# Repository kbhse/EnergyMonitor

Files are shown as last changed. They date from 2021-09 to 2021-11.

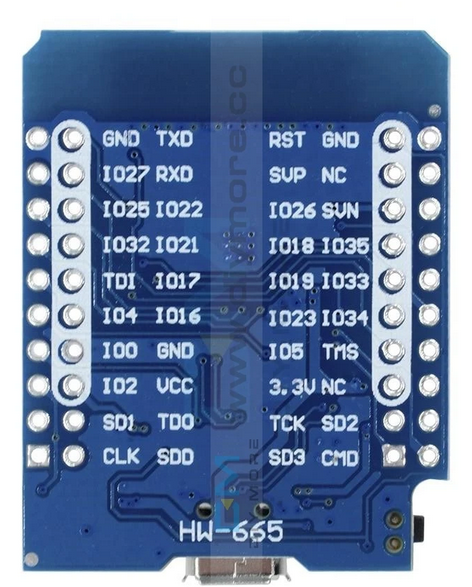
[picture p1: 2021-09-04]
KiCad/v1.1/images/Aideepen Wemos D1 ESP32.PNG

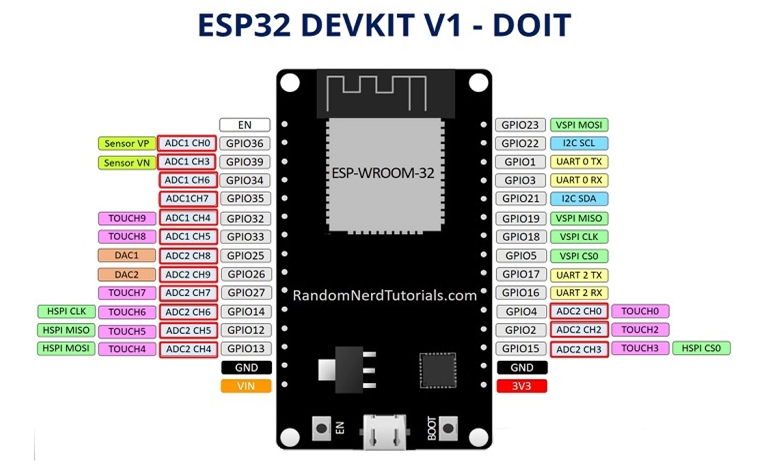
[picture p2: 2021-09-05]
KiCad/v1.1/images/ESP32_DEVKIT_V1.png

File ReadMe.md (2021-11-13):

pcb 3D 02

 &nbsp;
 
* Schematic and PCB design in [KiCad](https://www.kicad.org/)

* Hardware design in [SolidWorks](https://www.solidworks.com/domain/design-engineering)

* C++ code on [PlatformIO](https://docs.platformio.org/en/latest/what-is-platformio.html) IDE

* 3D prints [Prusa i3 MK3S+](https://www.prusa3d.com)

&nbsp;

 **ESP32 based energy monitor**

Samples voltage and current waveform at 2500 Hz.
The voltage waveform is sampled from an AC/AC 9v wallplug adapter and the current waveforms with current transformers clamped round live (or neutral) conductors.

Capacity: 240v, 3 circuits up tp 95 amps each.

Intergrated into a [MQTT](https://en.wikipedia.org/wiki/MQTT) [IoT](https://en.wikipedia.org/wiki/Internet_of_things) sensor network with [Node-RED](https://nodered.org/), [InfluxDB](https://www.influxdata.com/) and [Grafana](https://grafana.com/) servers.

Uses the [EmonLib library](https://github.com/openenergymonitor/EmonLib)

[An Introduction to AC Power](https://learn.openenergymonitor.org/electricity-monitoring/ac-power-theory/introduction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)

The **ESP32** is a low-cost, low-power [system on a chip](https://en.wikipedia.org/wiki/System_on_a_chip "System on a chip") [microcontroller](https://en.wikipedia.org/wiki/Microcontroller "Microcontroller") with integrated Wi-Fi, created and developed by Espressif Systems



Specification:

- Xtensa dual-core 32-bit LX6 microprocessor
- 240 MHz
- 520 KiB SRAM, 448 KiB ROM, 16 KiB SRAM in RTC
- Ultra low power co-processor
- Wi-Fi: 802.11 b/g/n
- 34 × programmable [GPIO](https://en.wikipedia.org/wiki/General-purpose_input/output)s
- 12-bit [SAR ADC](https://en.wikipedia.org/wiki/Successive-approximation_ADC) up to 18 channels
- 2 × 8-bit [DAC](https://en.wikipedia.org/wiki/Digital-to-analog_converter)s
- 10 × touch sensors (capacitive sensing GPIOs)
- 4 × [SPI](https://en.wikipedia.org/wiki/Serial_Peripheral_Interface)
- 2 × [I²S](https://en.wikipedia.org/wiki/I%C2%B2S) interfaces
- 2 × [I²C](https://en.wikipedia.org/wiki/I%C2%B2C) interfaces
- 3 × [UART](https://en.wikipedia.org/wiki/Universal_asynchronous_receiver-transmitter)
- SD/SDIO/CE-ATA/MMC/eMMC host controller
- SDIO/SPI slave controller
- Ethernet MAC interface with dedicated DMA and IEEE 1588
- Precision Time Protocol support
- [CAN bus](https://en.wikipedia.org/wiki/CAN_bus) 2.0
- Infrared remote controller (TX/RX, up to 8 channels)
- Motor [PWM](https://en.wikipedia.org/wiki/Pulse-width_modulation)
- LED PWM (up to 16 channels)
- [Hall effect](https://en.wikipedia.org/wiki/Hall_effect) sensor
- Ultra low power analog pre-amplifier
- IEEE 802.11 standard security features all supported, including [WPA](https://en.wikipedia.org/wiki/Wi-Fi_Protected_Access), - [WPA2](https://en.wikipedia.org/wiki/Wi-Fi_Protected_Access), [WPA3](https://en.wikipedia.org/wiki/Wi-Fi_Protected_Access) and [WAPI](https://en.wikipedia.org/wiki/WLAN_Authentication_and_Privacy_Infrastructure)
- [Secure boot](https://docs.espressif.com/projects/esp-idf/en/latest/esp32/security/secure-boot-v1.html)
- [Flash encryption](https://docs.espressif.com/projects/esp-idf/en/latest/esp32/security/flash-encryption.html)
- 1024-bit [OTP](https://en.wikipedia.org/wiki/One-time_password)
- Cryptographic hardware acceleration: [AES](https://en.wikipedia.org/wiki/Advanced_Encryption_Standard), [SHA-2](https://en.wikipedia.org/wiki/SHA-2), [RSA](https://en.wikipedia.org/wiki/RSA_(cryptosystem)), [elliptic curve cryptography (ECC)](https://en.wikipedia.org/wiki/Elliptic-curve_cryptography), [random number generator (RNG)](https://en.wikipedia.org/wiki/Random_number_generation)
- Internal [low-dropout regulator](https://en.wikipedia.org/wiki/Low-dropout_regulator)
- Individual power domain for [RTC](https://en.wikipedia.org/wiki/Real-time_clock)
- 5 μA deep sleep current
- Wake up from GPIO interrupt, timer, ADC measurements, capacitive touch sensor interrupt

&nbsp;

**PCB:**

- CAD: [KiCad](https://www.kicad.org/)
- Production: [JLCPCB](https://jlcpcb.com/)

pcb 3D

board

board

GndA

PCB_GNDA

Gnd

PCB_GND

[JLCPCB](https://jlcpcb.com/)

pcb

Production Progress

20210930_182721_50%

20211003_025516_50%

20211003_025620_50%

&nbsp;

**Case design** (WIP):

CAD: [SolidWorks](https://www.solidworks.com/domain/design-engineering)

Slicer: [PrusaSlicer](https://www.prusa3d.com/prusaslicer/)

Printer: [Prusa i3 MK3S+](https://www.prusa3d.com)

- Material: E-DA [PLA](https://en.wikipedia.org/wiki/Polylactic_acid)
- Nozzle: 0.4mm
- Layer Height: 0.2mm
- Infill: 20% cubic
- Support: optional
- Filament: 21m, 63g
- Print Time: 5hr 48m

Dimensions (LxWxH): 110x58x35 mm

EnergyMonitor Case v1 2 transparent

EnergyMonitor Case v1 2



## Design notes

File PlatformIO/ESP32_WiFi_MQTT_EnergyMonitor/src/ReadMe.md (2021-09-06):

Notes:

- [x] use a different library for SHT30 (with crc error checking)

- [x] make wifi and mqtt non-blocking

WiFi:

https://www.esp8266.com/viewtopic.php?p=71077

https://arduino-esp8266.readthedocs.io/en/latest/esp8266wifi/generic-examples.html

MQTT:

https://github.com/knolleary/pubsubclient/blob/master/examples/mqtt_reconnect_nonblocking/mqtt_reconnect_nonblocking.ino

3. remote reboot ESP32

4. PID control

5. sht30 sample rate & I2C speed vs cable length https://github.com/espressif/arduino-esp32/issues/1395

6. pubsub qos http://www.steves-internet-guide.com/using-arduino-pubsub-mqtt-client/

7. 06/01/21 19:00 v01.04 running

8. Sometimes getting -54 on ssrState! use boolean data type

9. if it restarts it will go back to default low and high setPoints !!! need NodeRED globals?

10. ~~do I need the wemos relay??~~

11. add remote restart via subscribe to topic ssrHeater1/restart

12. perhaps it should check for setPoints regularly (if mqtt not reliable and it doesn't update from Node-RED publish)

Don't block critical thermostat function !!

non-blocking WiFi:

If connection is established, and then lost for some reason, ESP will automatically reconnect to the last used access point once it is again back on-line. This will be done automatically by Wi-Fi library, without any user intervention.
So the old code would only be blocking on startup or restart (in setup() call to setup_wifi()) if there is no WiFi because code is waiting to report that the connection has been established.
This code: `while (WiFi.status() != WL_CONNECTED)` could loop forever if no WiFi connection established.
Don't need to report connection established so just get rid of that code.

NB test it works if ESP8266 starts up with no WiFi available. does a blink in loop work?

for an event driven solution that reports connection/disconnection without blocking critical functionality

see : https://arduino-esp8266.readthedocs.io/en/latest/esp8266wifi/readme.html#quick-start

non-blocking mqtt https://github.com/knolleary/pubsubclient/blob/master/examples/mqtt_reconnect_nonblocking/mqtt_reconnect_nonblocking.ino

ChangeLog

01.00

01.05 change default setPoints

01.06 added publish (re)start message (to track restarts) in setup()

01.07 on (re)startup (in setup()) publish request for the current setPoints but don't wait for them (non-blocking).

they will overwrite the defaults in callback() if/when messages arrive. take care in NodeRED that the values won't fail the sanity check (in callback()) which would revert to defaults!

PROBLEM WITH MQTT MULTIPLE CONNECTIONS:

change the ESP device ID

Here's how it looks:

	if (client.connect("ESP8266Client")) {

Can do it like this:

	if (client.connect("ESP1_Office")) {

Then, for the other ESP:

	if (client.connect("ESP2_Garage")) {

That should solve MQTT multiple connections problem.

- [x] If it starts without a wifi signal need code in loop() to periodically try to connect, simlar to MQTT server connection

- [x] change name from client to MQTTclient

- [ ] setup in weatherstation

- [x] callback in energy monitor

MQTT:

https://github.com/knolleary/pubsubclient

https://randomnerdtutorials.com/raspberry-pi-publishing-mqtt-messages-to-esp8266/

EmonLib:

https://savjee.be/2019/07/Home-Energy-Monitor-ESP32-CT-Sensor-Emonlib/

- [ ] grafana mqtt buttons
- [ ] calculate power factors in Node-RED instead of mcu

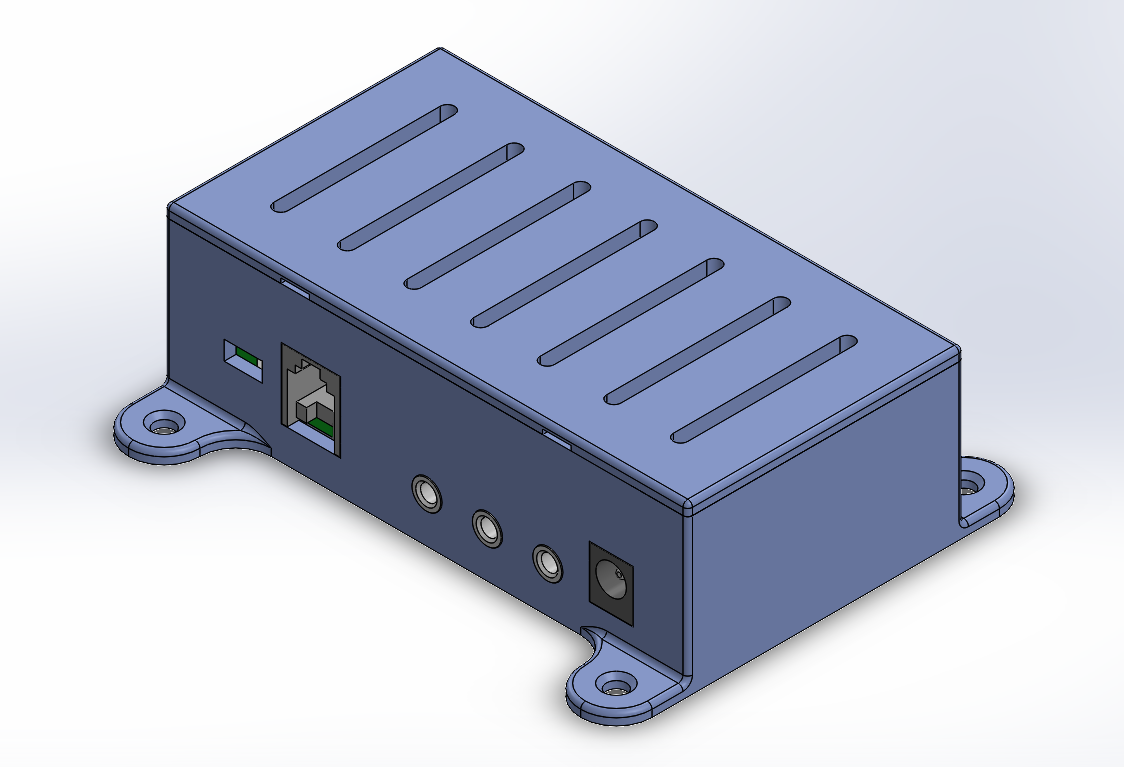
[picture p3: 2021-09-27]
Solidworks/images/EnergyMonitor Case v1.0.PNG

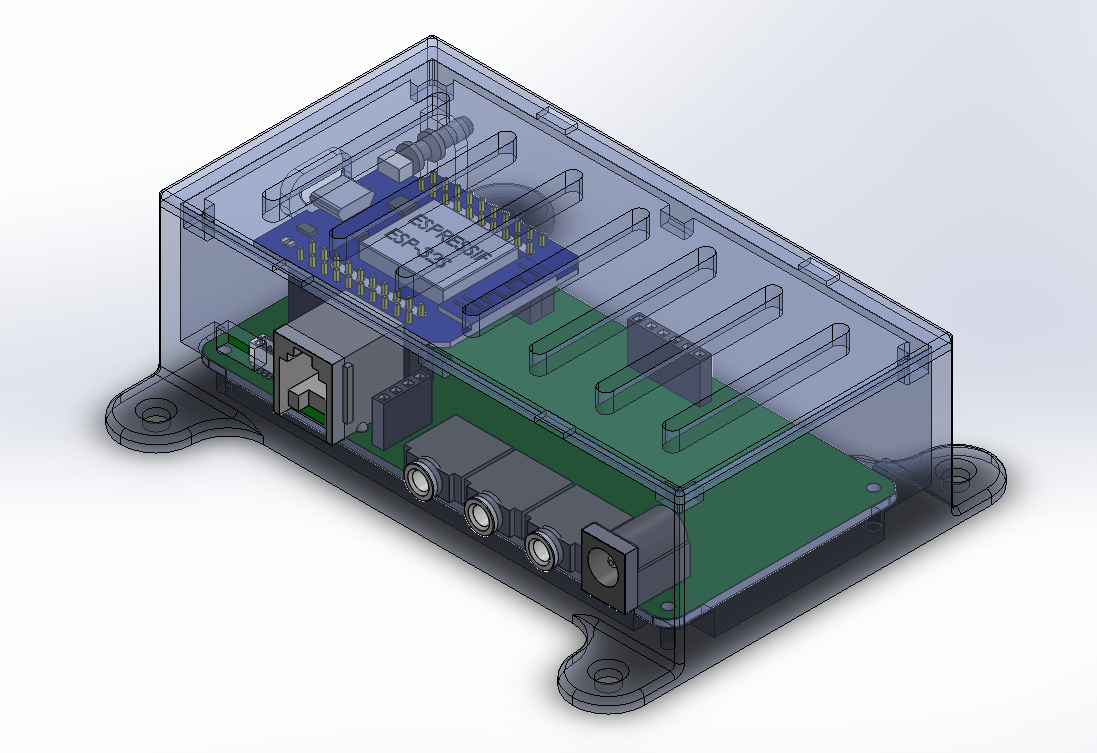
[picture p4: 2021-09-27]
Solidworks/images/EnergyMonitor Case v1.0 transparent.PNG

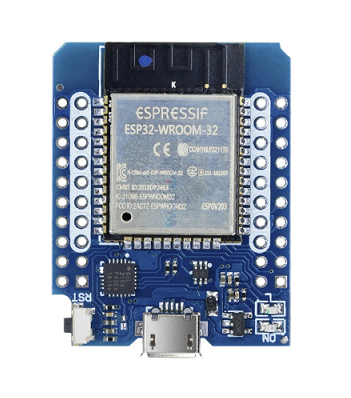
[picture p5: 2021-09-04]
KiCad/v1.1/images/Aideepen Wemos D1 ESP32_top.PNG

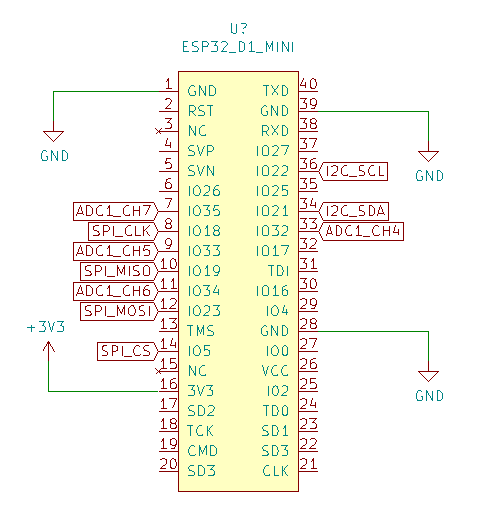
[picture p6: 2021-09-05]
KiCad/v1.1/images/ESP32_D1_MINI Symbol.PNG

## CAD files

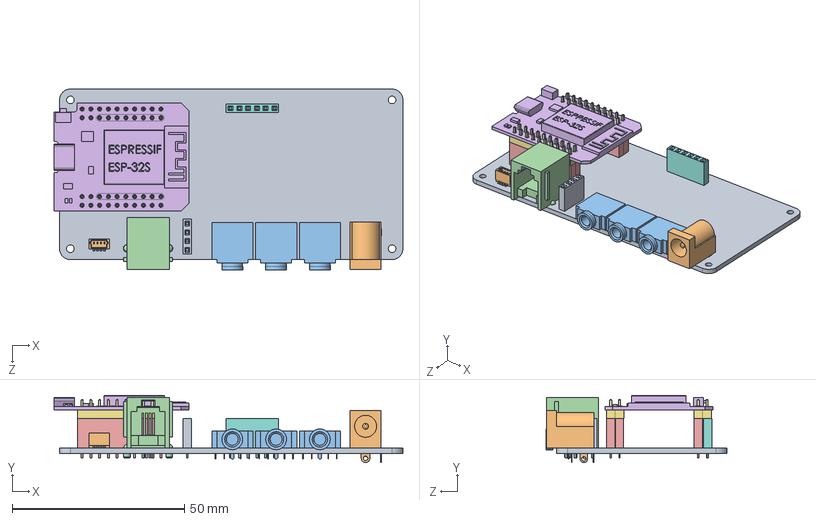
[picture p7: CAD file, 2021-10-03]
Solidworks/pcb_v1.0.SLDASM
101.3 x 19.5 x 52.5 mm
pcb_v1.0
5.5x2.1mm 3P DC Power Jack PCB Mount Female Socket
PCB Mount 3.5mm 5 Pin Socket x 3
RJ9 4P4C (#C026)
header sockets 1x10 x 4
ESP32 D1 mini
header pins 1x10 x 4
header sockets 1x6
header sockets 1x4
JST_SH_BM04B_SRDD_TB_04x1.00mm

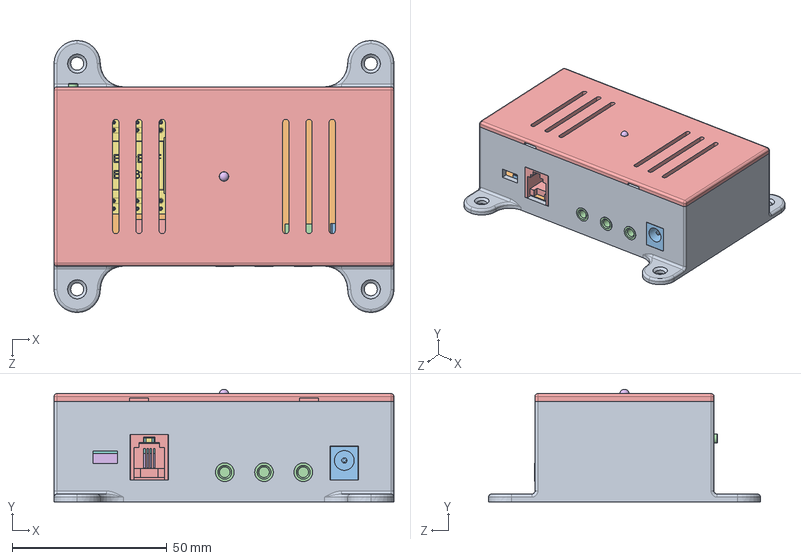
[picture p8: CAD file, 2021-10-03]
Solidworks/EnergyMonitor v1.2.SLDASM
110.0 x 36.4 x 88.0 mm
EnergyMonitor Case v1.2
pcb_v1.0
5.5x2.1mm 3P DC Power Jack PCB Mount Female Socket
PCB Mount 3.5mm 5 Pin Socket x 3
RJ9 4P4C (#C026)
header sockets 1x10 x 4
ESP32 D1 mini
header pins 1x10 x 4
header sockets 1x6
header sockets 1x4
JST_SH_BM04B_SRDD_TB_04x1.00mm
reset pin
EnergyMonitor Case top v1.2
LED

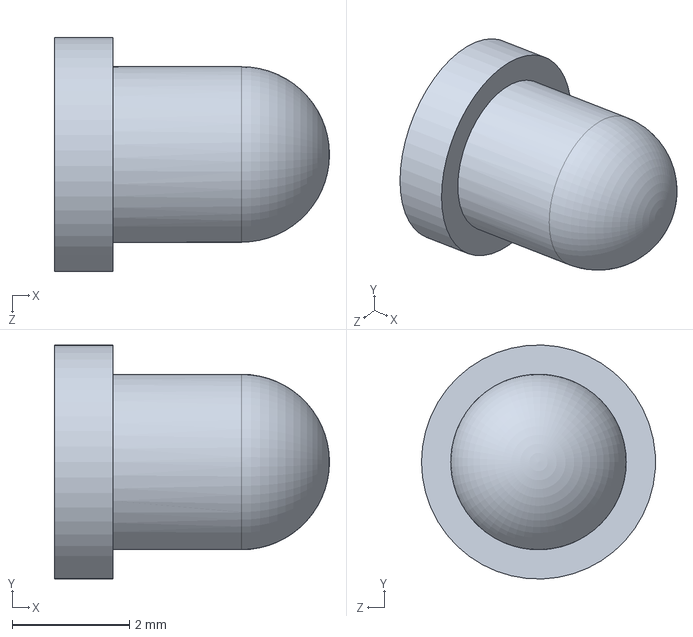
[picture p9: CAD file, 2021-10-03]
Solidworks/LED.SLDPRT
4.70 x 4.00 x 4.00 mm

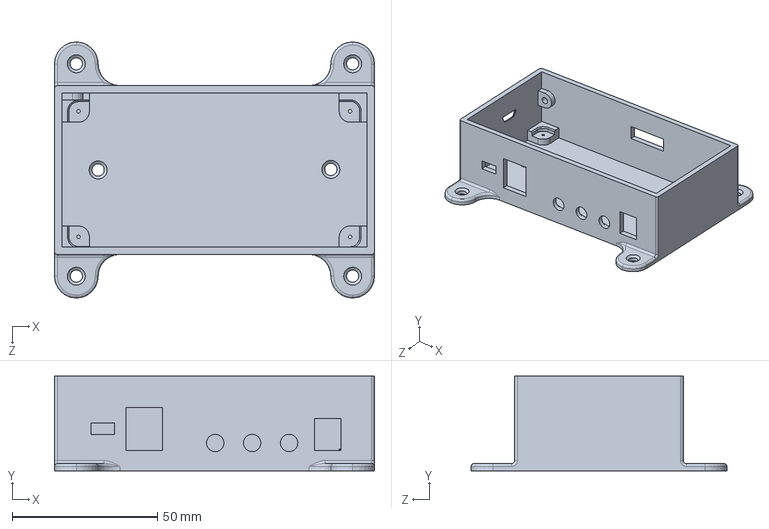
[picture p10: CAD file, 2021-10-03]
Solidworks/EnergyMonitor Case v1.2.SLDPRT
110.0 x 32.5 x 88.0 mm

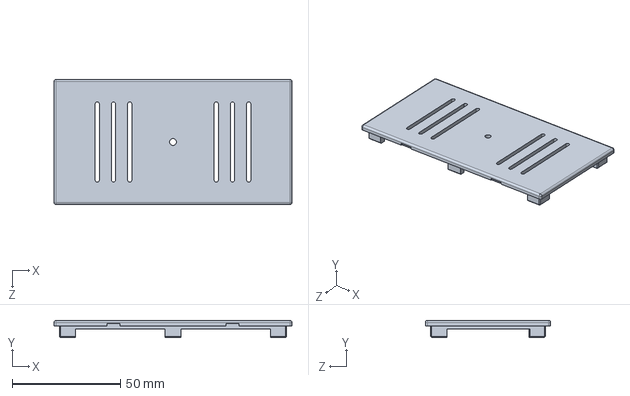
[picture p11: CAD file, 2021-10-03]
Solidworks/EnergyMonitor Case top v1.2.SLDPRT
110.0 x 8.00 x 58.0 mm

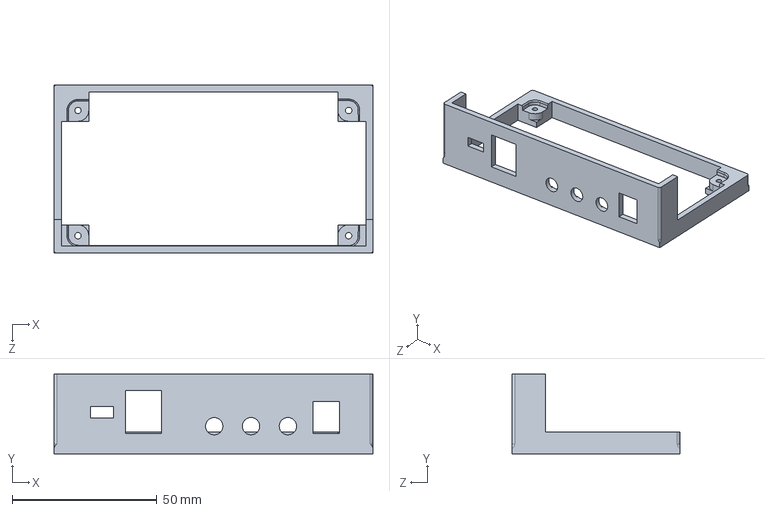
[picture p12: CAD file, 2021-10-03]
Solidworks/EnergyMonitor Case v1.0 jig.SLDPRT
110.0 x 27.5 x 58.0 mm

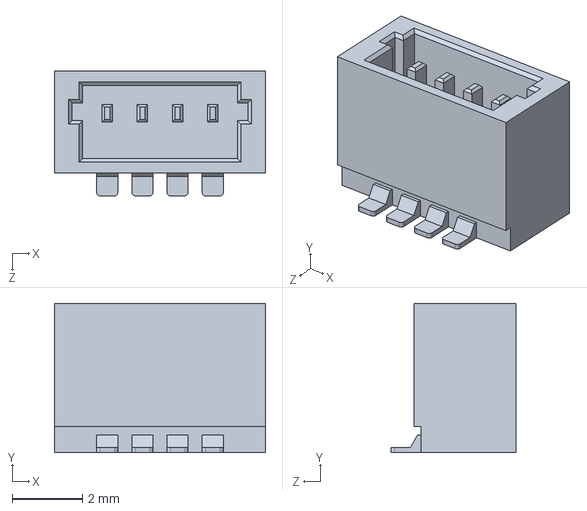
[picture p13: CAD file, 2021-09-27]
Solidworks/JST_SH_BM04B_SRDD_TB_04x1.00mm.SLDPRT
6.00 x 4.25 x 3.55 mm

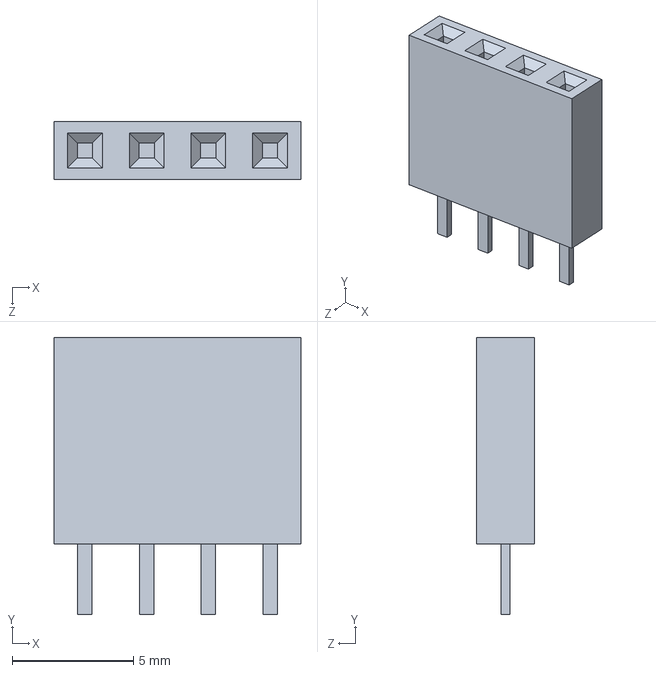
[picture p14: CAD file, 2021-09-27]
Solidworks/header sockets 1x4.SLDPRT
10.2 x 11.4 x 2.40 mm

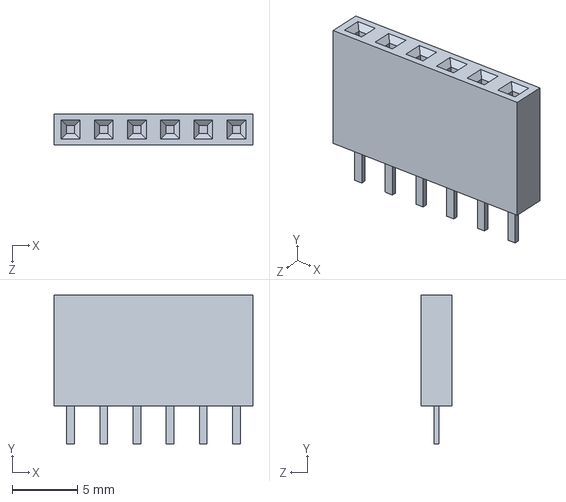
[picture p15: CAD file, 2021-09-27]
Solidworks/header sockets 1x6.SLDPRT
15.2 x 11.4 x 2.40 mm

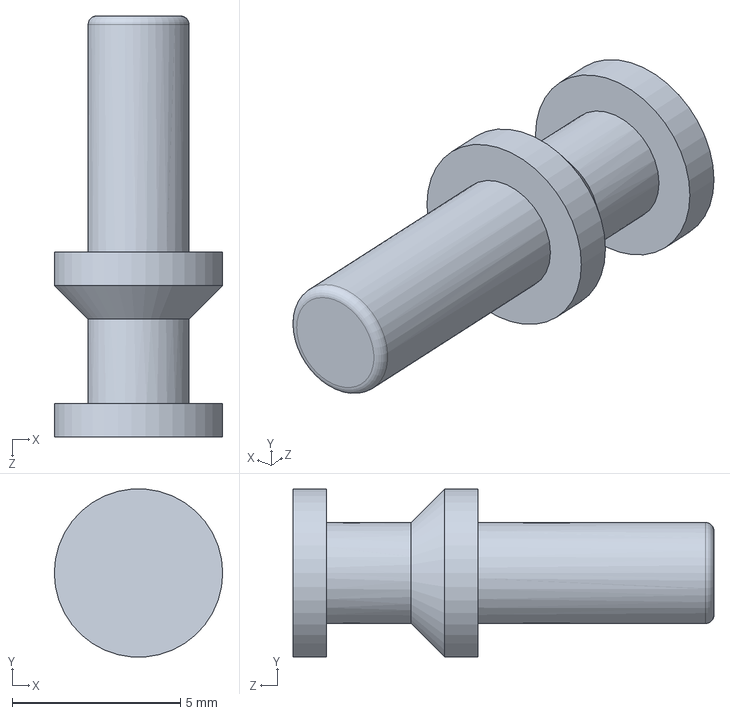
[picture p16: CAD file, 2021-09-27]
Solidworks/reset pin.SLDPRT
5.00 x 4.98 x 12.5 mm

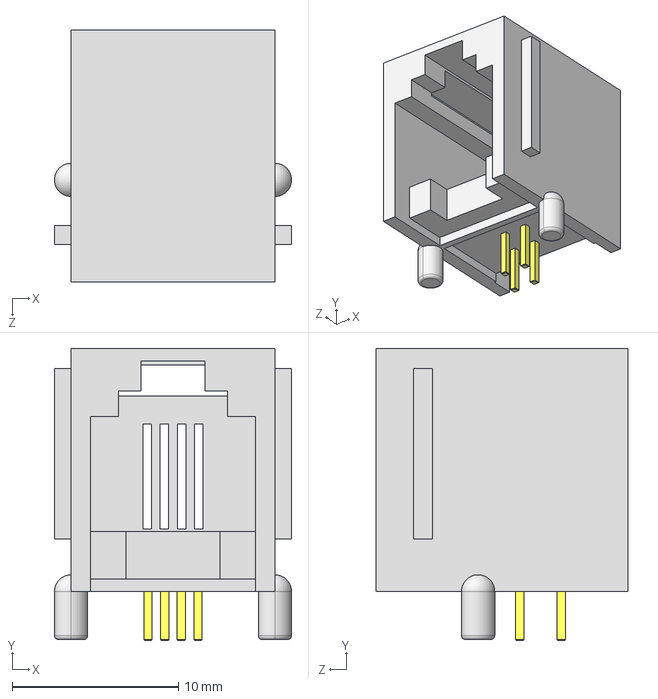
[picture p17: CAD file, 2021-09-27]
Solidworks/RJ9 4P4C (#C026).STEP
14.3 x 17.5 x 15.1 mm

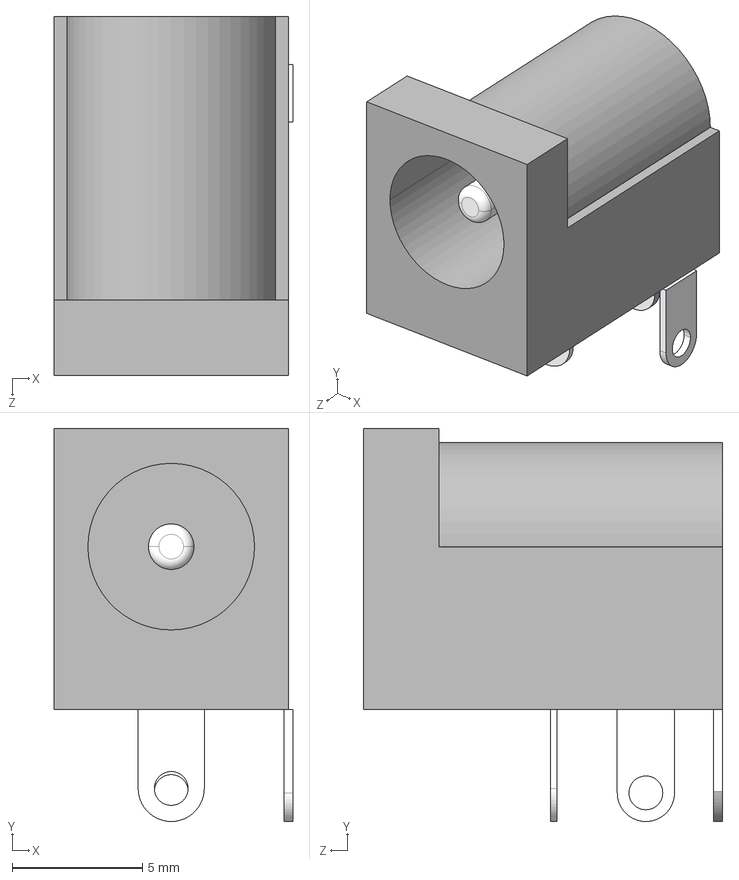
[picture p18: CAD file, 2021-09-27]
Solidworks/5.5x2.1mm 3P DC Power Jack PCB Mount Female Socket.STEP
9.17 x 15.1 x 13.8 mm

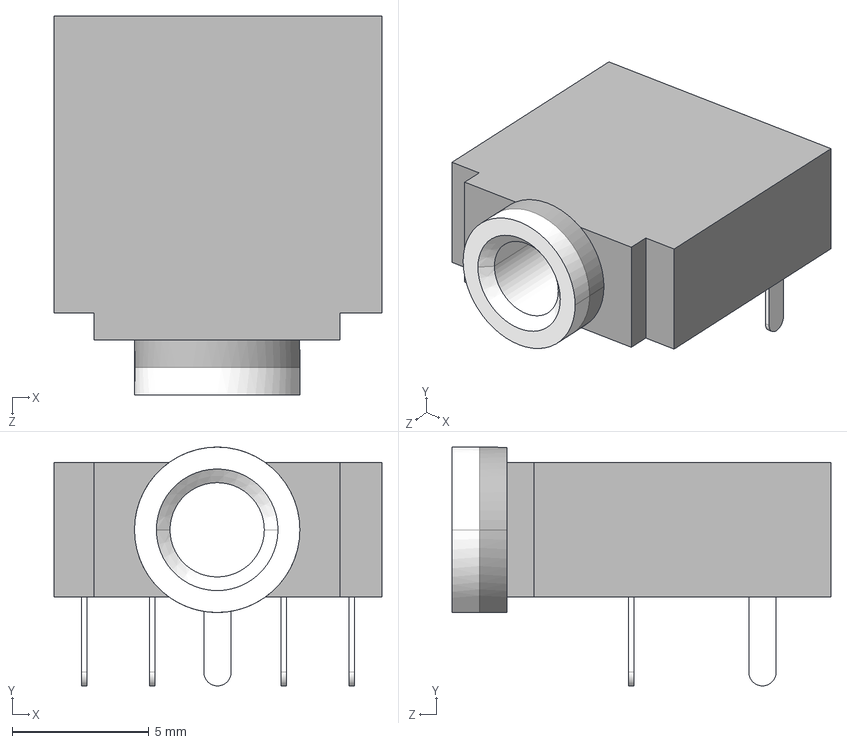
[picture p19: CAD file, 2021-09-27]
Solidworks/PCB Mount 3.5mm 5 Pin Socket.STEP
12.0 x 8.74 x 13.8 mm

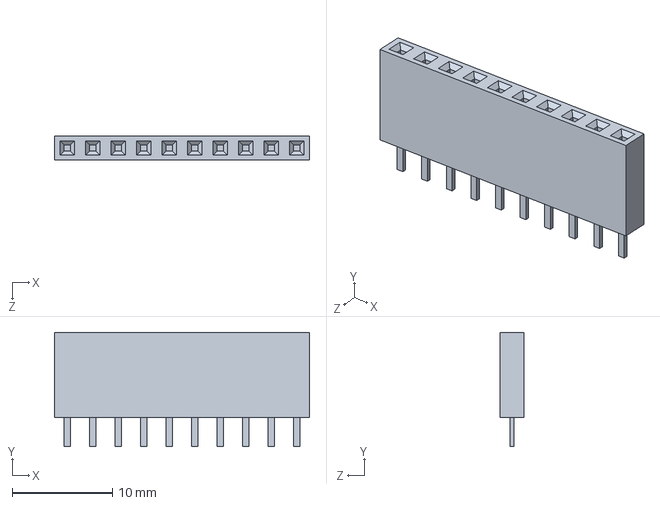
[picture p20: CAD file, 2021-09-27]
Solidworks/header sockets 1x10.SLDPRT
25.4 x 11.4 x 2.40 mm

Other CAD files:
Solidworks/header pins 1x10.SLDPRT
Solidworks/ESP32 D1 mini.STEP
Solidworks/EnergyMonitor v1.0.SLDASM
Solidworks/EnergyMonitor Case top v1.1.SLDPRT
Solidworks/5.5x2.1mm 3P DC Power Jack PCB Mount Female Socket.SLDPRT
Solidworks/ESP32 D1 mini.SLDASM
Solidworks/ESP32 D1 mini.SLDPRT
Solidworks/EnergyMonitor Case top v1.0.SLDPRT
Solidworks/EnergyMonitor Case v1.0.SLDPRT
Solidworks/PCB Mount 3.5mm 5 Pin Socket.SLDPRT
Solidworks/RJ9 4P4C (#C026).SLDPRT
Solidworks/pcb_v1.0.SLDPRT
Solidworks/stl/EnergyMonitor Case top v1.0.STL
Solidworks/stl/EnergyMonitor Case top v1.1.STL
Solidworks/stl/EnergyMonitor Case top v1.2.STL
Solidworks/stl/EnergyMonitor Case v1.0 jig.SLDPRT
Solidworks/stl/EnergyMonitor Case v1.0 jig.STL
Solidworks/stl/EnergyMonitor Case v1.0.STL
Solidworks/stl/EnergyMonitor Case v1.2.STL
Solidworks/stl/reset pin.STL

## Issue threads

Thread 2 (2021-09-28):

v1.0 Case design

kbhse, 2021-09-28:
front exit for JST SH 4 pin connector cable for I2C
rear exit for JST XH 6 pin connector cable for GPIO/SPI
plugs for exits when not in use
recesses for captive M2 hex nuts
adjust height
provision for (some interchangable) labels for ports
reset pin
LED on outer surface?

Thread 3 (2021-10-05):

Powering ESP32 D1 mini from external 3.3v supply

kbhse, 2021-10-05:
This doesn't work. Perhaps removing LDO from ESP32 D1 mini might work but not a great solution as would need external (non USB) power supply when programming ESP32.

Try replacing HT7333 3.3V LDO with HT7350 SOT-89 5V LDO and jumper to VCC input on ESP32 D1 mini.
HT7350 on order.

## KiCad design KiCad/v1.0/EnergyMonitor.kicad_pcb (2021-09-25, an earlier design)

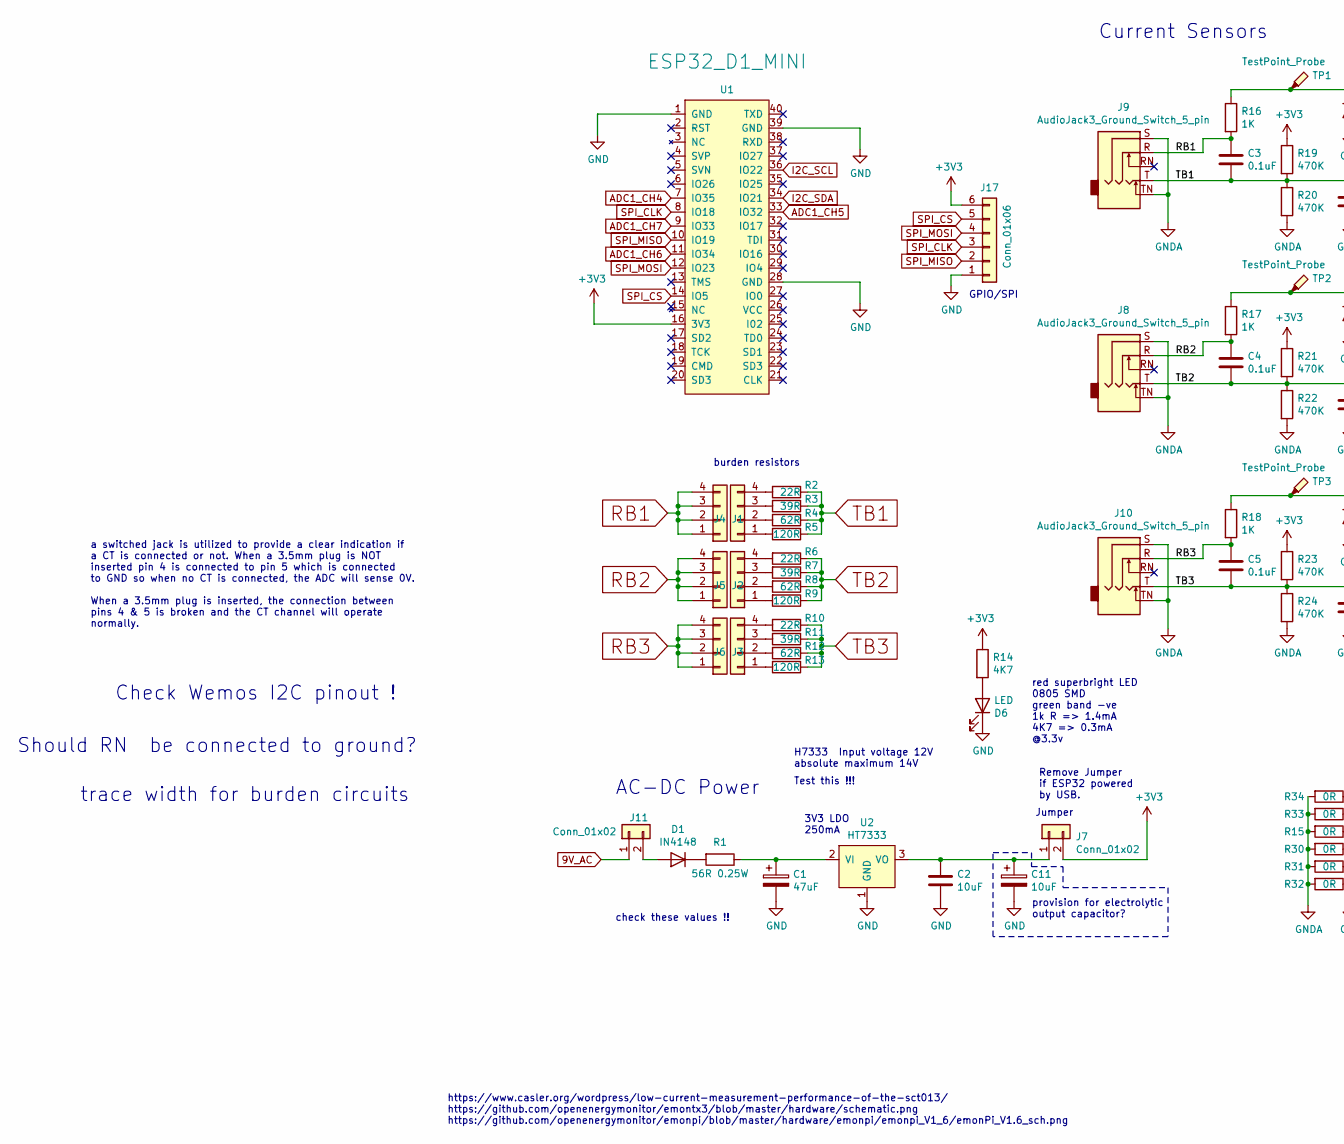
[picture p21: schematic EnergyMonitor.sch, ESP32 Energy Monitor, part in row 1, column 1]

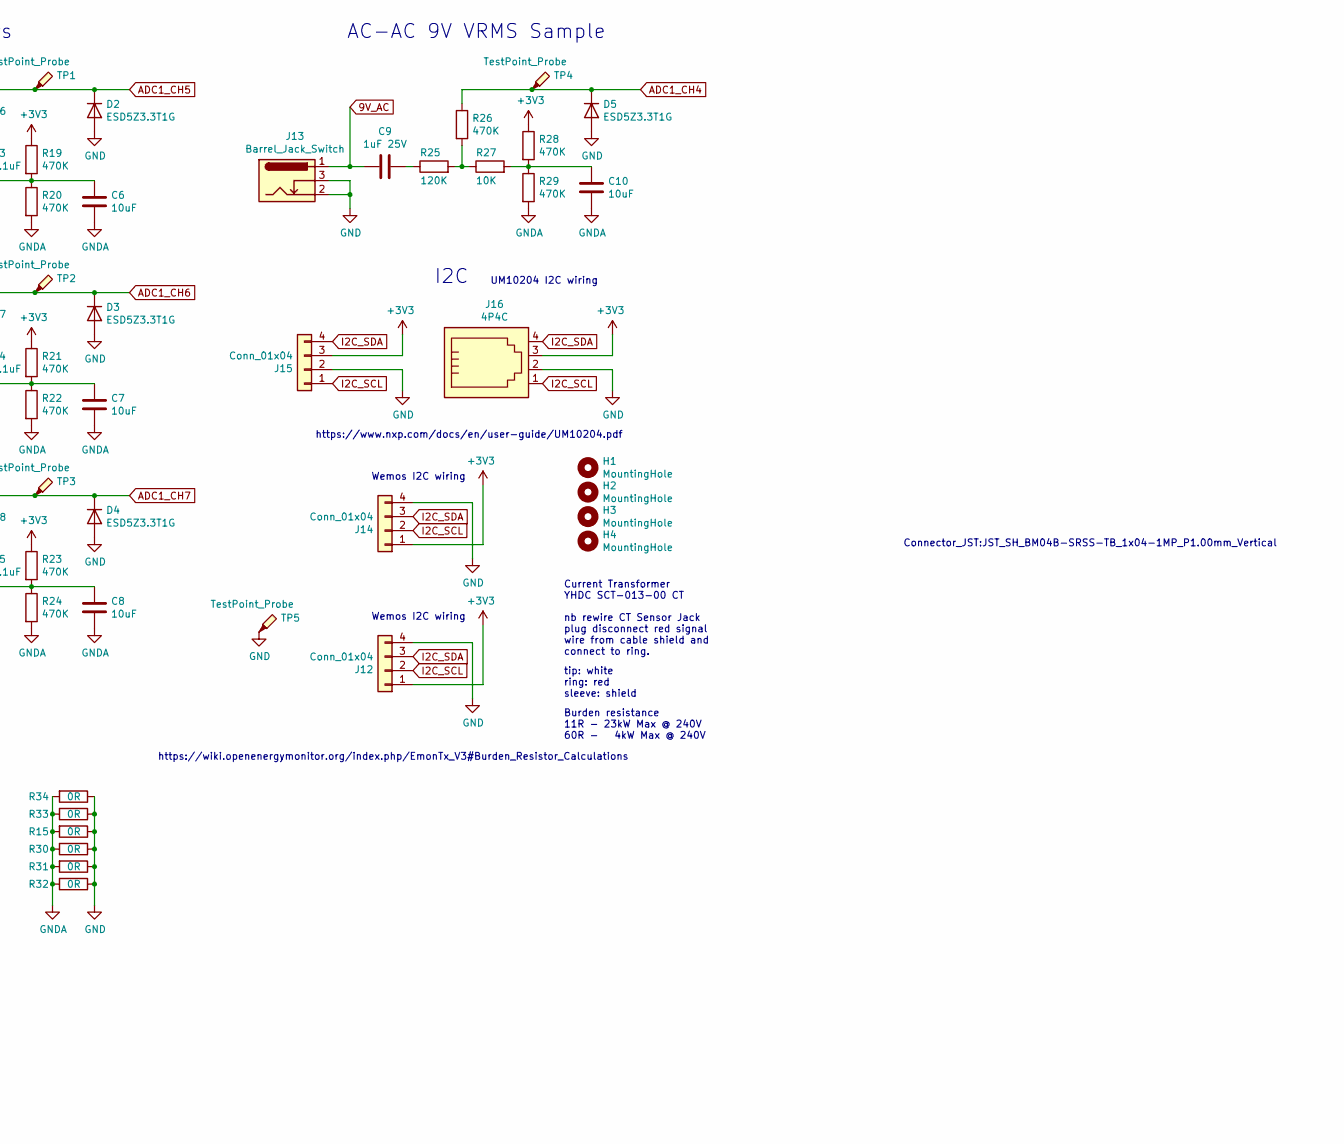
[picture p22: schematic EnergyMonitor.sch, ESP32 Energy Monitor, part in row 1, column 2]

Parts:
C1: 47uF; CP_Elec_6.3x5.9
C2, C6, C7, C8, C10: 10uF; C_1206_3216Metric
C3, C4, C5: 0.1uF; C_0805_2012Metric
C9: 1uF 25V; C_0805_2012Metric
C11: 10uF; CP_Elec_6.3x5.9
D1: IN4148; D_DO-35_SOD27_P7.62mm_Horizontal
D2, D3, D4, D5: ESD5Z3.3T1G; D_SOD-523
D6: LED; LED_0805_2012Metric
H1, H2, H3, H4: MountingHole; MountingHole_2.2mm_M2_Pad_Via
J1, J2, J3, J4, J5, J6, J15: Conn_01x04; PinHeader_1x04_P2.54mm_Vertical
J7, J11: Conn_01x02; PinHeader_1x02_P2.54mm_Vertical
J8, J9, J10: AudioJack3_Ground_Switch_5_pin; 3.5mm_5_Pin_Socket_PCB_Mount
J12: Conn_01x04; JST_SH_SM04B-SRSS-TB_1x04-1MP_P1.00mm_Horizontal
J13: Barrel_Jack_Switch; DC_Barrel_Jack_Socket
J14: Conn_01x04; JST_SH_BM04B-SRSS-TB_1x04-1MP_P1.00mm_Vertical
J16: 4P4C; RJ6_4P4C_small_I2C_UM10204
J17: Conn_01x06; PinHeader_1x06_P2.54mm_Vertical
R1: 56R 0.25W; R_1206_3216Metric
R2, R6, R10: 22R; R_1206_3216Metric
R3, R7, R11: 39R; R_1206_3216Metric
R4, R8, R12: 62R; R_1206_3216Metric
R5, R9, R13: 120R; R_1206_3216Metric
R14: 4K7; R_0805_2012Metric
R15, R30, R31, R32, R33, R34: 0R; R_0805_2012Metric
R16, R17, R18: 1K; R_0805_2012Metric
R19, R20, R21, R22, R23, R24, R26, R28, R29: 470K; R_0805_2012Metric
R25: 120K; R_0805_2012Metric
R27: 10K; R_0805_2012Metric
TP1, TP2, TP3, TP4, TP5: TestPoint_Probe; TestPoint_Loop_D2.50mm_Drill1.0mm_LowProfile
U1: ESP32_D1_MINI
U2: HT7333; SOT-89-3

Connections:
9V_AC: C9.2, J11.1, J13.1
+3V3: J7.2, J12.1, J14.1, J15.3, J16.3, J17.6, R14.1, R19.1, R21.1, R23.1, R28.1, U1.16 (3V3)
ADC1_CH4: D5.1 (K), R26.1, TP4.1, U1.7 (IO35)
ADC1_CH5: D2.1 (K), R16.1, TP1.1, U1.33 (IO32)
ADC1_CH6: D3.1 (K), R17.1, TP2.1, U1.11 (IO34)
ADC1_CH7: D4.1 (K), R18.1, TP3.1, U1.9 (IO33)
GND: C1.2, C2.2, C11.2, D2.2 (A), D3.2 (A), D4.2 (A), D5.2 (A), D6.1 (K), J12.4, J13.2, J13.3, J14.4, J15.2, J16.2, J17.1, R15.1, R30.1, R31.1, R32.1, R33.1, R34.1, TP5.1, U1.1 (GND), U1.28 (GND), U1.39 (GND), U2.1 (GND)
GNDA: C6.2, C7.2, C8.2, C10.2, J8.S, J8.TN, J9.S, J9.TN, J10.S, J10.TN, R15.2, R20.2, R22.2, R24.2, R29.2, R30.2, R31.2, R32.2, R33.2, R34.2
I2C_SCL: J12.2, J14.2, J15.1, J16.1, U1.36 (IO22)
I2C_SDA: J12.3, J14.3, J15.4, J16.4, U1.34 (IO21)
unnamed: C1.1, R1.1, U2.2 (VI)
unnamed: C9.1, R25.1
unnamed: C10.1, R27.2, R28.2, R29.1
unnamed: C2.1, C11.1, J7.1, U2.3 (VO)
unnamed: D1.1 (K), R1.2
unnamed: D1.2 (A), J11.2
unnamed: D6.2 (A), R14.2
unnamed: J4.1, R5.2
unnamed: J4.2, R4.2
unnamed: J4.3, R3.2
unnamed: J4.4, R2.2
unnamed: J5.1, R9.2
unnamed: J5.2, R8.2
unnamed: J5.3, R7.2
unnamed: J5.4, R6.2
unnamed: J6.1, R13.2
unnamed: J6.2, R12.2
unnamed: J6.3, R11.2
unnamed: J6.4, R10.2
unnamed: R25.2, R26.2, R27.1
RB1: C3.1, J1.1, J1.2, J1.3, J1.4, J9.R, R16.2
RB2: C4.1, J2.1, J2.2, J2.3, J2.4, J8.R, R17.2
RB3: C5.1, J3.1, J3.2, J3.3, J3.4, J10.R, R18.2
SPI_CLK: J17.3, U1.8 (IO18)
SPI_CS: J17.5, U1.14 (IO5)
SPI_MISO: J17.2, U1.10 (IO19)
SPI_MOSI: J17.4, U1.12 (IO23)
TB1: C3.2, C6.1, J9.T, R2.1, R3.1, R4.1, R5.1, R19.2, R20.1
TB2: C4.2, C7.1, J8.T, R6.1, R7.1, R8.1, R9.1, R21.2, R22.1
TB3: C5.2, C8.1, J10.T, R10.1, R11.1, R12.1, R13.1, R23.2, R24.1

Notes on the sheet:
Current Transformer YHDC SCT-013-00 CT
tip: white ring: red sleeve: shield
nb rewire CT Sensor Jack plug disconnect red signal wire from cable shield and connect to ring.
AC-AC 9V VRMS Sample
Current Sensors
https://www.casler.org/wordpress/low-current-measurement-performance-of-the-sct013/ https://github.com/openenergymonitor/emontx3/blob/master/hardware/schematic.png https://github.com/openenergymonitor/emonpi/blob/master/hardware/emonpi/emonpi_V1_6/emonPi_V1.6_sch.png
3V3 LDO 250mA
Jumper
AC-DC Power
check these values !!
Remove Jumper if ESP32 powered by USB.
Burden resistance 11R - 23kW Max @ 240V 60R - 4kW Max @ 240V
I2C
https://www.nxp.com/docs/en/user-guide/UM10204.pdf
https://wiki.openenergymonitor.org/index.php/EmonTx_V3#Burden_Resistor_Calculations
a switched jack is utilized to provide a clear indication if a CT is connected or not. When a 3.5mm plug is NOT inserted pin 4 is connected to pin 5 which is connected to GND so when no CT is connected, the ADC will sense 0V. When a 3.5mm plug is inserted, the connection between pins 4 & 5 is broke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
burden resistors
Wemos I2C wiring
UM10204 I2C wiring
Check Wemos I2C pinout !
Should RN be connected to ground?
trace width for burden circuits
red superbright LED 0805 SMD green band -ve 1k R => 1.4mA 4K7 => 0.3mA @3.3v
Connector_JST:JST_SH_BM04B-SRSS-TB_1x04-1MP_P1.00mm_Vertical
GPIO/SPI
H7333 Input voltage 12V absolute maximum 14V
Test this !!!
provision for electrolytic output capacitor?

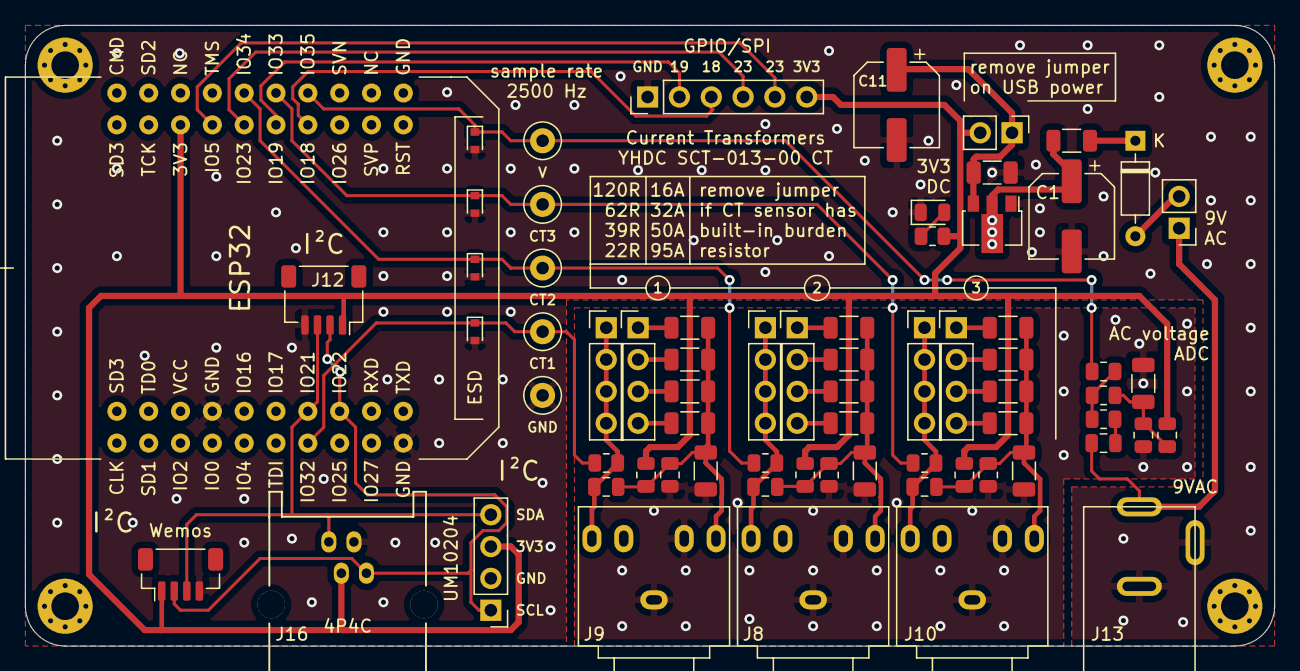
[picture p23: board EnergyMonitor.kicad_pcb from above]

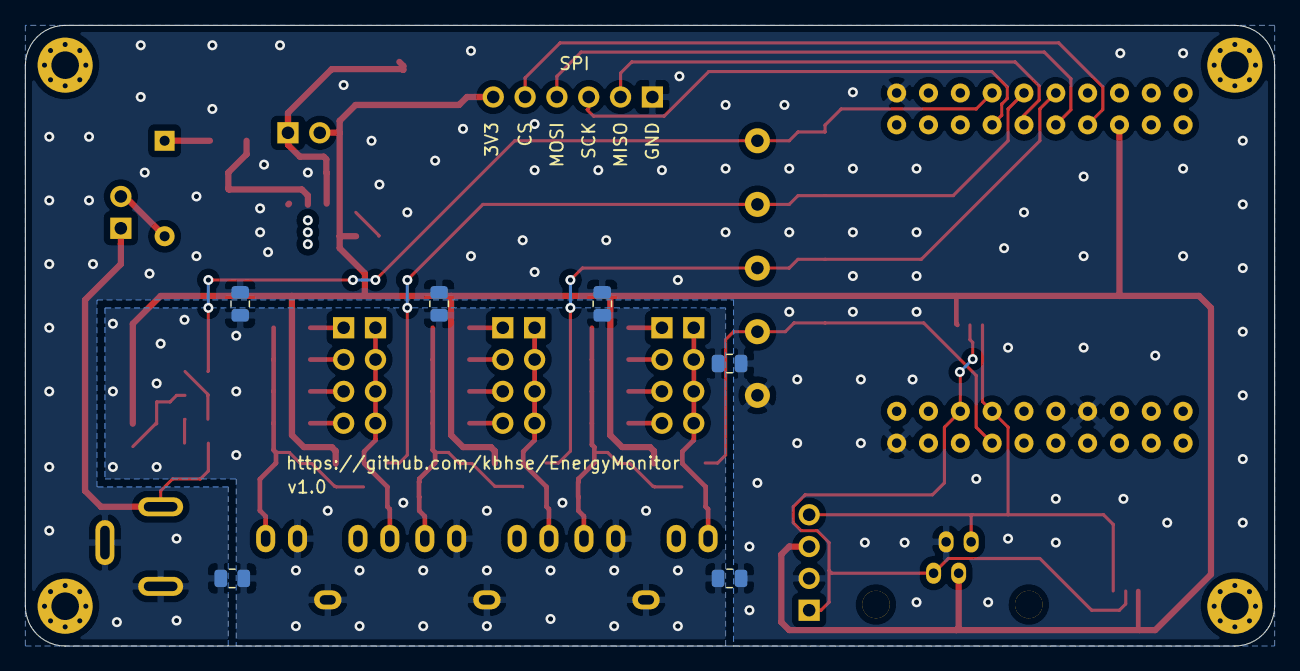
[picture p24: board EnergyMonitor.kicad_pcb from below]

Board: 2 copper layers, 99.7 x 49.5 mm, 79 parts (6 on the bottom side), 40 nets.

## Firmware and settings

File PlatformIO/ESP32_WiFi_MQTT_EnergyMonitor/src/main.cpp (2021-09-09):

#include <Arduino.h>
#include "SimpleTimer.h"                                                                            // https://playground.arduino.cc/Code/SimpleTimer/ https://github.com/marcelloromani/arduino/tree/master/SimpleTimer
#include "EmonLib.h"                                                                                // https://github.com/openenergymonitor/EmonLib
#include <driver/adc.h>                                                                             // for ESP32

#include "config.h"
#include "WiFiMQTT.h"

// Force EmonLib to use 10bit ADC resolution
#define ADC_BITS    10
#define ADC_COUNTS  (1<<ADC_BITS)

// ------------------------------------------------------------------
// Create Instances
        
WiFiClient PUB_SUB_CLIENT;
PubSubClient client(PUB_SUB_CLIENT);
SimpleTimer timer;
EnergyMonitor emon1;

long updateFreq = 1000;                                                      // DEFAULT update frequency for sensors and publish to MQTT (milliseconds)
int timerID;
bool restartFlg;                                                             // used to flag restarts so reconnect() will publish notification of restart to MQTT topic /sysMessage
long lastMqttReconnectAttempt = 0;

// ------------------------------------------------------------------
void setup()
  {
    
  Serial.begin(115200);
  //#ifdef DEBUG_OUT
      Serial.printf("\n\n%s_%s, %s, %s, %s, %s\n\n", PROGNAM, VERSION, AUTHOR, CREATION_DATE, MQTT_DEVICE, MQTT_LOCATION);
  //#endif

  adc1_config_channel_atten(ADC1_CHANNEL_6, ADC_ATTEN_DB_11);
  analogReadResolution(10);

  // Initialize emon library
  emon1.current(ADC_INPUT, CALIBRATION);

  pinMode(lamp, OUTPUT);                                                       // onboard LED
  #ifdef LED_STARTS_OFF
    digitalWrite(lamp, HIGH);                                                  // turn onboard LED OFF
  #endif

  connect_wifi();                             // NB as non-blocking, do I need a delay here?  test it

  client.setServer(mqttServer, mqttPort);
  client.setCallback(callback);

  // start the timer
  timerID = timer.setInterval(updateFreq, readSensors);                        // every x milliseconds, send data to MQTT

  id();

  restartFlg = true;

  }

// ------------------------------------------------------------------
void loop()
    {

    // non-blocking MQTT connection/reconnection                                 https://github.com/knolleary/pubsubclient/blob/master/examples/mqtt_reconnect_nonblocking/mqtt_reconnect_nonblocking.ino
    if (!client.connected())
        {
        // MQTT client is not connected
        long now = millis();
        if (now - lastMqttReconnectAttempt > 10000)                                // every 10 seconds
            {
            lastMqttReconnectAttempt = now;
            if (reconnect())                                                       // Attempt to reconnect
                {
                // 
                lastMqttReconnectAttempt = 0;
                }
            }
        }
    else
        {
        // MQTT client is connected
        client.loop();
        }

    timer.run();

    }

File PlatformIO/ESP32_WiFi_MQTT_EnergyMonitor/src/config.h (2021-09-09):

/* config.h */

#ifndef CONFIG_H   /* include guards */
#define CONFIG_H

    #include <Arduino.h>
    #include "credentials.h"

    #define PROGNAM "ESP32_WiFi_MQTT_ENERGYMONITOR"                                                     // program name
    #define VERSION "v0.12.1"                                                                           // program version (nb lowercase 'version' is keyword)
    #define PGMFUNCT ""                                                                                 // what the program does
    #define AUTHOR "klomar"                                                                             // created by
    #define CREATION_DATE "17 August 2021"                                                              // date
    #define MODIFIED_DATE "9 September 2021"
    #define DEBUG_OUT



    #define ADC_INPUT 34                            // the GPIO pin where the CT sensor is connected
    #define HOME_VOLTAGE 243                        // the house voltage
    #define CALIBRATION 29                          // the calibration number for the SCT-013-030 Current sensor
                                                    // 1800 turns / 62 ohms

    const int lamp = LED_BUILTIN;
    //long MQTTupdateFreq = 10000;                    // 1 minute (the update frequency to publish data to MQTT (milliseconds))
    //#define UPDATE_FREQ 60000L                      // 60 seconds

    // ------------------------------------------------------------------
    // MCU Hardware

    //#define MCU "ESP8266 D1 Mini"
    //#define MCU "ESP8266 D1 Mini Pro V2"
    #define MCU "ESP32 Dev board"
    //#define MCU "ESP32 D1 Mini"

    // ------------------------------------------------------------------
    // Configure MQTT
    // (unique identity for each ESP32 device)

        #define MQTT_DEVICE "esp031"                                                                       // MQTT requires unique device ID (see reconnect() function)
        #define PUB_SUB_CLIENT esp031client                                                                // and unique client ?
        #define MQTT_LOCATION "roaming31"                                                                  // location for MQTT topic

    // ------------------------------------------------------------------
    // Comment out sensors not in use

        //#define WEMOS_SHT30 "SHT30 "                                                                              // Wemos Temperature and Humidity shield
        //#define WEMOS_HP303 "HP303 "                                                                              // Wemos Barometric Pressure Shield
        //#define WEMOS_BH1750 "BH1750 "                                                                            // Wemos Ambient Light Shield
        //#define WEMOS_BATTERY "BATTERY "                                                                          // Wemos Battery Shield
        //#define WIFI_RSSI "RSSI "                                                                                 // ESP8266 WiFi RSSI
        //#define RS485_WIND "WIND "                                                                                // Anemometer and Wind Direction
        //#define CO2 "CO2 "                                                                                        // sandbox electronics CO2 sensor - NB recalibrate in fresh air regularly
        //#define ROBOTDYN_ACDIMMER "ACDIMMER "                                                                     // Robotdyn zero-crossing detector and AC dimmer module
        //#define MLX90614_IR_SENSOR "IR "                                                                          // IR temp sensor
        //#define DS18B20 "DS18B20"                                                                                 // 1-wire temperature sensor
        #define CURRENT_SENSOR                                                                                      // YHDC SCT-013 CT Sensor
        //#define ADC_TEST                                                                                          // test

/*
    // ------------------------------------------------------------------------------------------------
    // TFT pins - see README.md

        #define TFT_CS D0  //for D1 mini or TFT I2C Connector Shield (V1.1.0 or later)
        #define TFT_DC D8  //for D1 mini or TFT I2C Connector Shield (V1.1.0 or later)
        #define TFT_RST -1 //for D1 mini or TFT I2C Connector Shield (V1.1.0 or later)
        #define TS_CS D3   //for D1 mini or TFT I2C Connector Shield (V1.1.0 or later)

*/
   
#endif // CONFIG_H

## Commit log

2021-09-04 fix url
    [EnergyMonitor.sch]
2021-09-04 created symbol for ESP32_D1_MINI
    [EnergyMonitor.sch]
2021-09-04 edit symbol for ESP32_D1_MINI
    [EnergyMonitor.sch]
2021-09-04 directory structure
    [EnergyMonitor.kicad_pcb, EnergyMonitor.sch, file613171B3.sch]
2021-09-05 updated schematic
    [EnergyMonitor.sch]
2021-09-05 footprint for ESP32_D1_MINI
    [EnergyMonitor.sch]
2021-09-05 edit ESP32_D1_MINI Symbol
    [EnergyMonitor.sch]
2021-09-06 Circuit design - schematic
    [EnergyMonitor.sch]
2021-09-06 Cicruit design - schematic
    [EnergyMonitor.kicad_pcb, EnergyMonitor.sch]
2021-09-07 pcb footprints
    [EnergyMonitor.kicad_pcb, EnergyMonitor.sch]
2021-09-08 pcb layout
    [EnergyMonitor.kicad_pcb]
2021-09-21 circuit design & pcb layout
    [EnergyMonitor.kicad_pcb, EnergyMonitor.sch]
2021-09-22 create 3D models for PCB components
    [EnergyMonitor.kicad_pcb, EnergyMonitor.sch]
2021-09-25 added 2nd I2C port
    [EnergyMonitor-B_Cu.gbr, EnergyMonitor-B_Mask.gbr, EnergyMonitor-B_Paste.gbr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]
2021-09-25 added GPIO/SPI port
    [EnergyMonitor.kicad_pcb, EnergyMonitor.sch]
2021-09-25 created Gerber and Drill files
    [EnergyMonitor-B_Cu.gbr, EnergyMonitor-B_Mask.gbr, EnergyMonitor-B_Paste.gbr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]
2021-09-25 fabrication gerbers v1.0
    [EnergyMonitor-B_Cu.gbr, EnergyMonitor-B_Mask.gbr, EnergyMonitor-B_Paste.gbr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]
2021-09-25 v1.0 pcb in production
2021-09-27 create v1.1 schematic and pcb. case design. add thermal relief to HT7333 on v1.1 pcb
    [5.5x2.1mm 3P DC Power Jack PCB Mount Female Socket.SLDPRT, 5.5x2.1mm 3P DC Power Jack PCB Mount Female Socket.STEP, ESP32 D1 mini.SLDASM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]
2021-09-27 v1.0 Case Design
    [ESP32 D1 mini.SLDASM, EnergyMonitor Case top v1.0.SLDPRT, EnergyMonitor Case top v1.0.STL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]
2021-10-03 pcb fabrication and assembly, case design
    [ESP32 D1 mini.SLDASM, EnergyMonitor Case top v1.1.SLDPRT, EnergyMonitor Case top v1.1.STL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]
